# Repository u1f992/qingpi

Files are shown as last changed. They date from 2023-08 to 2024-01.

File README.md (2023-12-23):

# Qingpi





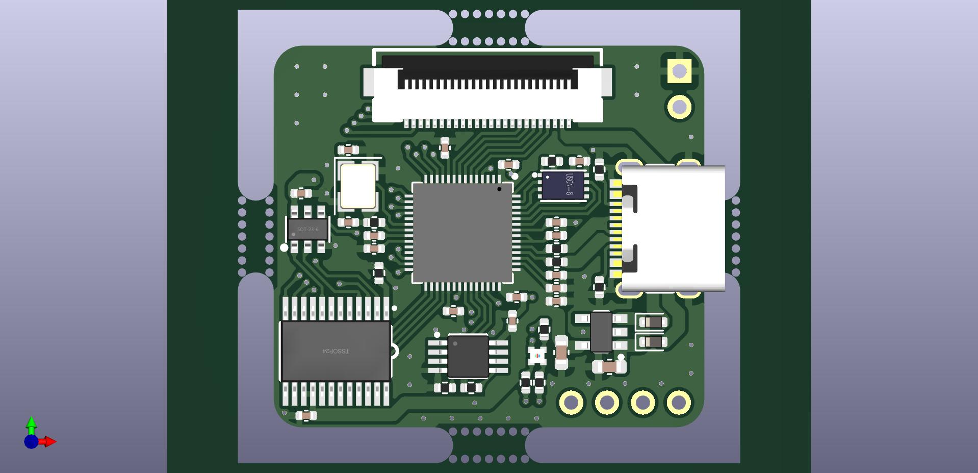
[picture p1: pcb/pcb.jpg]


Qingpi aka NeoCtrlMod is a project for externally controlling the Nintendo 3DS.

- PCB, FPC, firmware, Python library and example application included.
- Small enough to fit in a original housing.
- Buttons, slide pad, and touch screen supported.
  - IR not yet supported, but connected (contributions welcome).
- Aim to be fully documented.

Currently FPC is provided only for 3DS XL.

## Origin of the name

Qing Pi (青皮) is a herbal remedy made from the peel of unripe citrus fruits. It is named after [Citra](https://citra-emu.org/), the famous 3DS emulator, and "Citra" is derived from "CTR", the model number of 3DS series.

## Disclaimer

This is an unofficial project and the author assumes no responsibility for any 3DS hardware modifications. Use at your own risk and discretion.

## Acknowledgments

- [3DS controller mod](https://3dscapture.com/controller/) by loopy
- [3xtDS](https://github.com/dekuNukem/3xtDS) by dekuNukem
- [Nu Hanafudaya](https://kokagem.sakura.ne.jp/font/hanafudaya/) font by さゆぬ

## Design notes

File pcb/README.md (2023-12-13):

# PCB

## JLCPCB order

### PCB

<dl>
<dt>PCB Thickness</dt><dd>1.0</dd>
<dt>Remove Order Number</dt><dd>Specify a location</dd>
<dt>PCB Remark</dt><dd>Holes in the four corners are for position calibration. NPTH&F.Mask&F.Paste, drill holes in both the PCB and the stencil.</dd>
</dl>

### PCBA

<dl>
<dt>PCBA Type</dt><dd>Economic</dd>
<dt>Confirm Parts Placement</dt><dd>Yes</dd>
</dl>

### Stencil

<dl>
<dt>Customized size</dt><dd>Yes 50*85mm</dd>
<dt>Stencil Side</dt><dd>Top</dd>
<dt>Confirm Production file</dt><dd>Yes</dd>
<dt>Stencil Remark</dt><dd>Holes in the four corners are for position calibration. NPTH&F.Mask&F.Paste, drill holes in both the PCB and the stencil.</dd>
</dl>

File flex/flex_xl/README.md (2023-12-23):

# FPC for 3DS XL

## JLCPCB order

<dl>
<dt>PCB Thickness</dt><dd>0.11</dd>
<dt>Gold Fingers</dt><dd>Yes</dd>
<dt>Gold Fingers Thickness</dt><dd>0.3</dd>
<dt>Stiffener</dt><dd>Polyimide</dd>
<dt>Polyimide Thickness</dt><dd>0.25mm</dd>
<dt>Confirm Production file</dt><dd>Yes</dd>
<dt>PCB Remark</dt><dd>

```
The placement instruction for the stiffener is included in flex-User-Comments.gbr.
Stick the stiffener on the front side.
Material : Polyimide
Required total thickness : 0.3mm
```

</dd>
</dl>

`Polyimide Thickness` can be calculated with the [PI Calculator](https://jlcpcb.com/gold-fingers-PI-thickness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). It says "PI stiffener theoretical thickness： 0.2295 mm, Recommended PI stiffener thickness： 0.25 mm".

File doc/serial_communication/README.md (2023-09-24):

# シリアル通信

通信のバイナリ構造は[NX Macro Controller](https://blog.bzl-web.com/entry/2020/01/20/165719)の方式[^7]に準拠します。パッド座標は左上起点で、ニュートラルポジションは128です。右パッドは将来の更新のために予約されています。

Switchのキーボード操作に使用されている末尾3バイトをタッチスクリーン操作に割り当てます。タッチ入力座標は左上起点で1 <= x <= 320、1 <= y <= 240の値を受け付けます。いずれかが範囲外の場合、タッチ入力を解除します。

| Index | Value |
| ----- | --- |
| 0 | 0xAB |
| 1 | Button lower |
| 2 | Button upper |
| 3 | Hat |
| 4 | Left pad X-axis |
| 5 | Left pad Y-axis |
| 6 | (Right pad X-axis) |
| 7 | (Right pad Y-axis) |
| 8 | Touch screen X-axis lower |
| 9 | Touch screen X-axis upper |
| 10 | Touch screen Y-axis |

ボタンは各ビットについて0を解放、1を押下とします。ZLとZRは将来の更新のために予約されています。対応するボタンが存在しないL ClickとR Clickには、電源とWi-Fi切替を割り当てています。

| Button (NXMC) | Bit mask |
| --- | --- |
| Y | 0b0000'0000'0000'0001 |
| B | 0b0000'0000'0000'0010 |
| A | 0b0000'0000'0000'0100 |
| X | 0b0000'0000'0000'1000 |
| L | 0b0000'0000'0001'0000 |
| R | 0b0000'0000'0010'0000 |
| (ZL) | 0b0000'0000'0100'0000 |
| (ZR) | 0b0000'0000'1000'0000 |
| (-) → Select | 0b0000'0001'0000'0000 |
| (+) → Start | 0b0000'0010'0000'0000 |
| (L Click) → Power | 0b0000'0100'0000'0000 |
| (R Click) → Wi-Fi | 0b0000'1000'0000'0000 |
| Home | 0b0001'0000'0000'0000 |
| (Capture) | 0b0010'0000'0000'0000 |

ハットの各方向の実体はボタンですが、押し方の組み合わせは機構上制限されています。

| Hat | Value |
| --- | ----- |
| ↑ | 0 |
| ↗ | 1 |
| → | 2 |
| ↘ | 3 |
| ↓ | 4 |
| ↙ | 5 |
| ← | 6 |
| ↖ | 7 |
| x | 8 |

[^7]: https://scrapbox.io/yatsuna827827-12010999/Nintendo_Switch%E3%82%92%E6%93%8D%E4%BD%9C%E3%81%99%E3%82%8B%E3%83%97%E3%83%AD%E3%82%B0%E3%83%A9%E3%83%A0%E3%81%AE%E4%BB%9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

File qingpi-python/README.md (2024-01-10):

# qingpi-python

Python library for Qingpi.

```shell-session
$ pip install qingpi-python
```

## qingpictl

GUI application to control Qingpi with transparent Window and Citra compatible keyboard operation.

Currently, only Windows version is available.

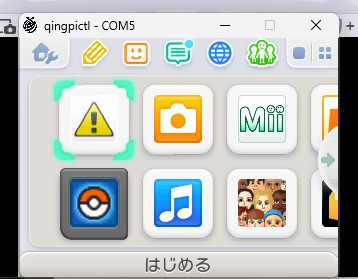
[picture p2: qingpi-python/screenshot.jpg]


### Run

```shell-session
$ qingpictl [port]
```

or

```shell-session
$ python -m qingpi [port]
```

or using pre-built binary

```shell-session
> qingpictl.exe [port]
```

You may create batch file like this if you don't want to specify the port from the command line every time.

```bat
START qingpictl.exe COM6
```

### Input mapping

<dl>
<dt>

Button

</dt>
<dd>

| Control  | Input |
| --- | :---: |
| A |  `A`  |
| B |  `S`  |
| X |  `Z`  |
| Y |  `X`  |
| L |  `Q`  |
| R |  `W`  |
| ~~ZL~~ |  `1`  |
| ~~ZR~~ |  `2`  |
| START |  `M`  |
| SELECT |  `N`  |
| HOME |  `B`  |
| POWER |  `V`  |
| WIRELESS |  `P`  |

</dd>
<dt>

Hat

</dt>
<dd>

| Control | Input |
| --- | :---: |
| UP |  `T`  |
| RIGHT |  `H`  |
| DOWN |  `G`  |
| LEFT |  `F`  |

</dd>
<dt>

SlidePad

</dt>
<dd>

| Control | Input |
| --- | :---: |
| UP |  `<Up>` |
| RIGHT | `<Right>` |
| DOWN | `<Down>`  |
| LEFT | `<Left>`  |

</dd>
<dt>

~~Circle Pad Pro~~ (not implemented)

</dt>
<dd>

| Control | Input |
| --- | :---: |
| ~~UP~~ |  `I`  |
| ~~RIGHT~~ |  `L`  |
| ~~DOWN~~  |  `K`  |
| ~~LEFT~~  |  `J`  |

</dd>
<dt>

Hotkeys

</dt>
<dd>

| Control | Input |
| --- | :---: |
| Expand window |  `+`  |
| Shrink window |  `-`  |

</dd>
</dl>

## Developer note

```shell-session
$ poetry run python -m qingpi [port] --debug
```

The build script requires PyInstaller and ImageMagick.

```shell-session
$ poetry run python -m pip install pyinstaller
$ make
```

PyInstaller is not included in the dev group because PyInstaller has a narrower Python version specification than necessary (e.g. v6.3.0 requires "<3.13,>=3.8"), which affects version reqirements of qingpi-python.

To avoid security issues,

```shell-session
$ poetry run python -m pip uninstall pyinstaller
$ git clone https://github.com/pyinstaller/pyinstaller --depth 1
$ cd .\pyinstaller\bootloader\
$ py .\waf distclean all
$ cd ..\..\
$ poetry run python -m pip install .\pyinstaller\
```

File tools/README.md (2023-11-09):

# tools

Tools for development.

```
poetry run python [script]
```

<dl>
<dt>

`calibrate_slidepad.py [port]`

</dt>
<dd>

Rotate the slidepad significantly along its circumference.

</dd>
<dt>

`plot_image.py [input] [port]`

</dt>
<dd>

Plot the image with dots.

</dd>
<dt>

`write_line.py [port]`

</dt>
<dd>

Draw crosshairs and outer border lines.

</dd>
</dl>

## Acknowledgments

- Emoji from [Fluent Emoji](https://github.com/microsoft/fluentui-emoji)

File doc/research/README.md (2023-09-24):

# 調査メモ

## 本体の選定

3DSシリーズにはいくつか種別があります。3DSと3DS LLではTPはほぼ共通[^1]です。New 3DS以降はTP番号がシルク印刷されていませんが、以下で紹介するほぼすべての要素に対応するTPおよびビア等が明らかになっています[^2]。

| 種別 | 特徴 |
| --- | --- |
| 3DS（o3DS） | 入手しやすい。キャプチャ基板の取り付けが比較的容易[^3]だが、本体内にスペースの余裕がない。 |
| 3DS LL（XL） | キャプチャ基板の取り付けが比較的容易[^4]で、本体内に基板を収める余裕がある。 |
| New 3DSシリーズ | 本体性能が向上し、New専用ソフトもある。<br>キャプチャ基板の取り付けが高難易度、現実的ではない[^5]。操作用のTP等も同様。 |
| 2DSシリーズ | （知見が少ないため除外） |

自動操作に対応できないゲームソフトが出てきますが、他改造との共存のしやすさと工作精度の懸念から、3DS LLをベースに開発を進めます。

[^1]: http://problemkaputt.de/gbatek-3ds-testpoints.htm
[^2]: http://imaginglabo.web.fc2.com/new3DSLL-barabara.html
[^3]: https://optimize.ath.cx/N-SPA3/index.htm
[^4]: https://optimize.ath.cx/LL-SPA3/index.htm
[^5]: https://optimize.ath.cx/NEW3DS/index.htm

## ボタン

| Function  | TP  |
| --- | --- |
| Y | 88  |
| B | 92  |
| A | 89  |
| X | 86  |
| L | 83  |
| R | 82  |
| Select | 81  |
| Start | 80  |
| Home | 55  |
| 電源 | 52  |
| Wi-Fi切替 | 58  |
| ↑ | 85  |
| → | 90  |
| ↓ | 91  |
| ← | 87  |

押下されることでランド同士が導通する一般的な構造です。15個のTPが露出しており、それぞれアクティブローのデジタル入力です。解放時は1.8V出力ではなくハイインピーダンス状態にすることで、レベル変換が不要になります。

## スライドパッド

| Function | TP  |
| --- | --- |
| X軸 | 69  |
| Y軸 | 68  |

2基のポテンショメータで構成されます。フレキシブルケーブルの4線は、GND、X軸出力、1.8V、Y軸出力に対応します。X軸は右から左、Y軸は下から上に0～1.8Vのアナログ入力です。



スライドパッドが取り付けられておりニュートラルポジションの状態では、各TPは約0.9Vの状態です。電圧を変化させるには、±250μAのシンク／ソースを切り替えられる、電流出力のD/Aコンバータが必要です。ニュートラルより右／下に動かすときはシンク電流で電圧を下げ、左／上に動かすときはソース電流で電圧を上げます。

## タッチスクリーン

| Function | TP  |
| --- | --- |
| X+ | 216 |
| X- | 215 |
| Y+ | 213 |
| Y- | 214 |

タッチスクリーンの原理として、X軸とY軸にそれぞれ1基のポテンショメータが搭載されており、押下されることでワイパー同士が接続される状態をイメージしてください。



3DSでは、4つのピンの機能を以下のように操作することで、押下の検出と各座標の取得を行います（指定のないピンはハイインピーダンス状態と考えられます）。

- Y+をプルアップ回路付きデジタル入力、X-をLOWとして押下を検知 → 以下の割り込み処理を発火
- X+をHIGH、X-をLOW、Y+をアナログ入力とすることで、X座標を取得
- Y+をHIGH、Y-をLOW、X+をアナログ入力とすることで、Y座標を取得

3xtDSではピンを監視し時間を計測してX+とY+に直接アナログ出力をしていましたが、マイクロ秒精度の制御が必要であるほか、タッチ入力がブロッキング処理になりタッチしながらほかの操作を受け付けられない、境界値付近の入力は困難という課題がありました。

このプロジェクトでは、X+〜X-間とY+〜Y-間にデジタルポテンショメータを接続し、ワイパー同士をリレーを挟んで接続します。リレーがオンになることでY+はLOWになり、両方向で分圧回路が成立します。解放時はリレーをオフにするとともにデジタルポテンショメータもシャットダウンすることで、本体のタッチ入力機能を維持できます。



3DS LLにおいて実際のタッチスクリーンの全抵抗値は、X軸方向が約460Ω、Y軸方向が約360Ωです。プルアップ抵抗値は不明ですが、全抵抗値が可能な限り低いデジタルポテンショメータを使用する必要があると考えられます。実験の結果、X軸に全抵抗値2kΩ、Y軸に1kΩのポテンショメータとするのは問題ないようです。

執筆時点で、市販品には1kΩ未満の高分解能なデジタルポテンショメータはありません。Y軸の240pxは8bitで対応できますが、X軸の320pxを指定するために、3基のポテンショメータを使用することで対処しています[^6]。

[^6]: https://www.analog.com/media/en/technical-documentation/application-notes/AN-582.pdf

## 拡張スライドパッド／赤外線

TP255に露出していることはわかっていますが、詳細はわかりません。

Controller Modには拡張スライドパッドのエミュレーション機能がありますが、もとがPSoCなうえアセンブリ言語も用いているので移植が困難です。PIOも別コアも空いているので、気概さえあれば実装できます。

## 電源

+5.0Vからマイコンに電力を供給します。

| 電圧 | TP  |
| ---- | --- |
| +5.0 | 32  |
| GND  | 1 |

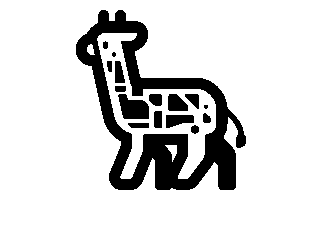
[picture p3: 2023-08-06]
tools/giraffe.png

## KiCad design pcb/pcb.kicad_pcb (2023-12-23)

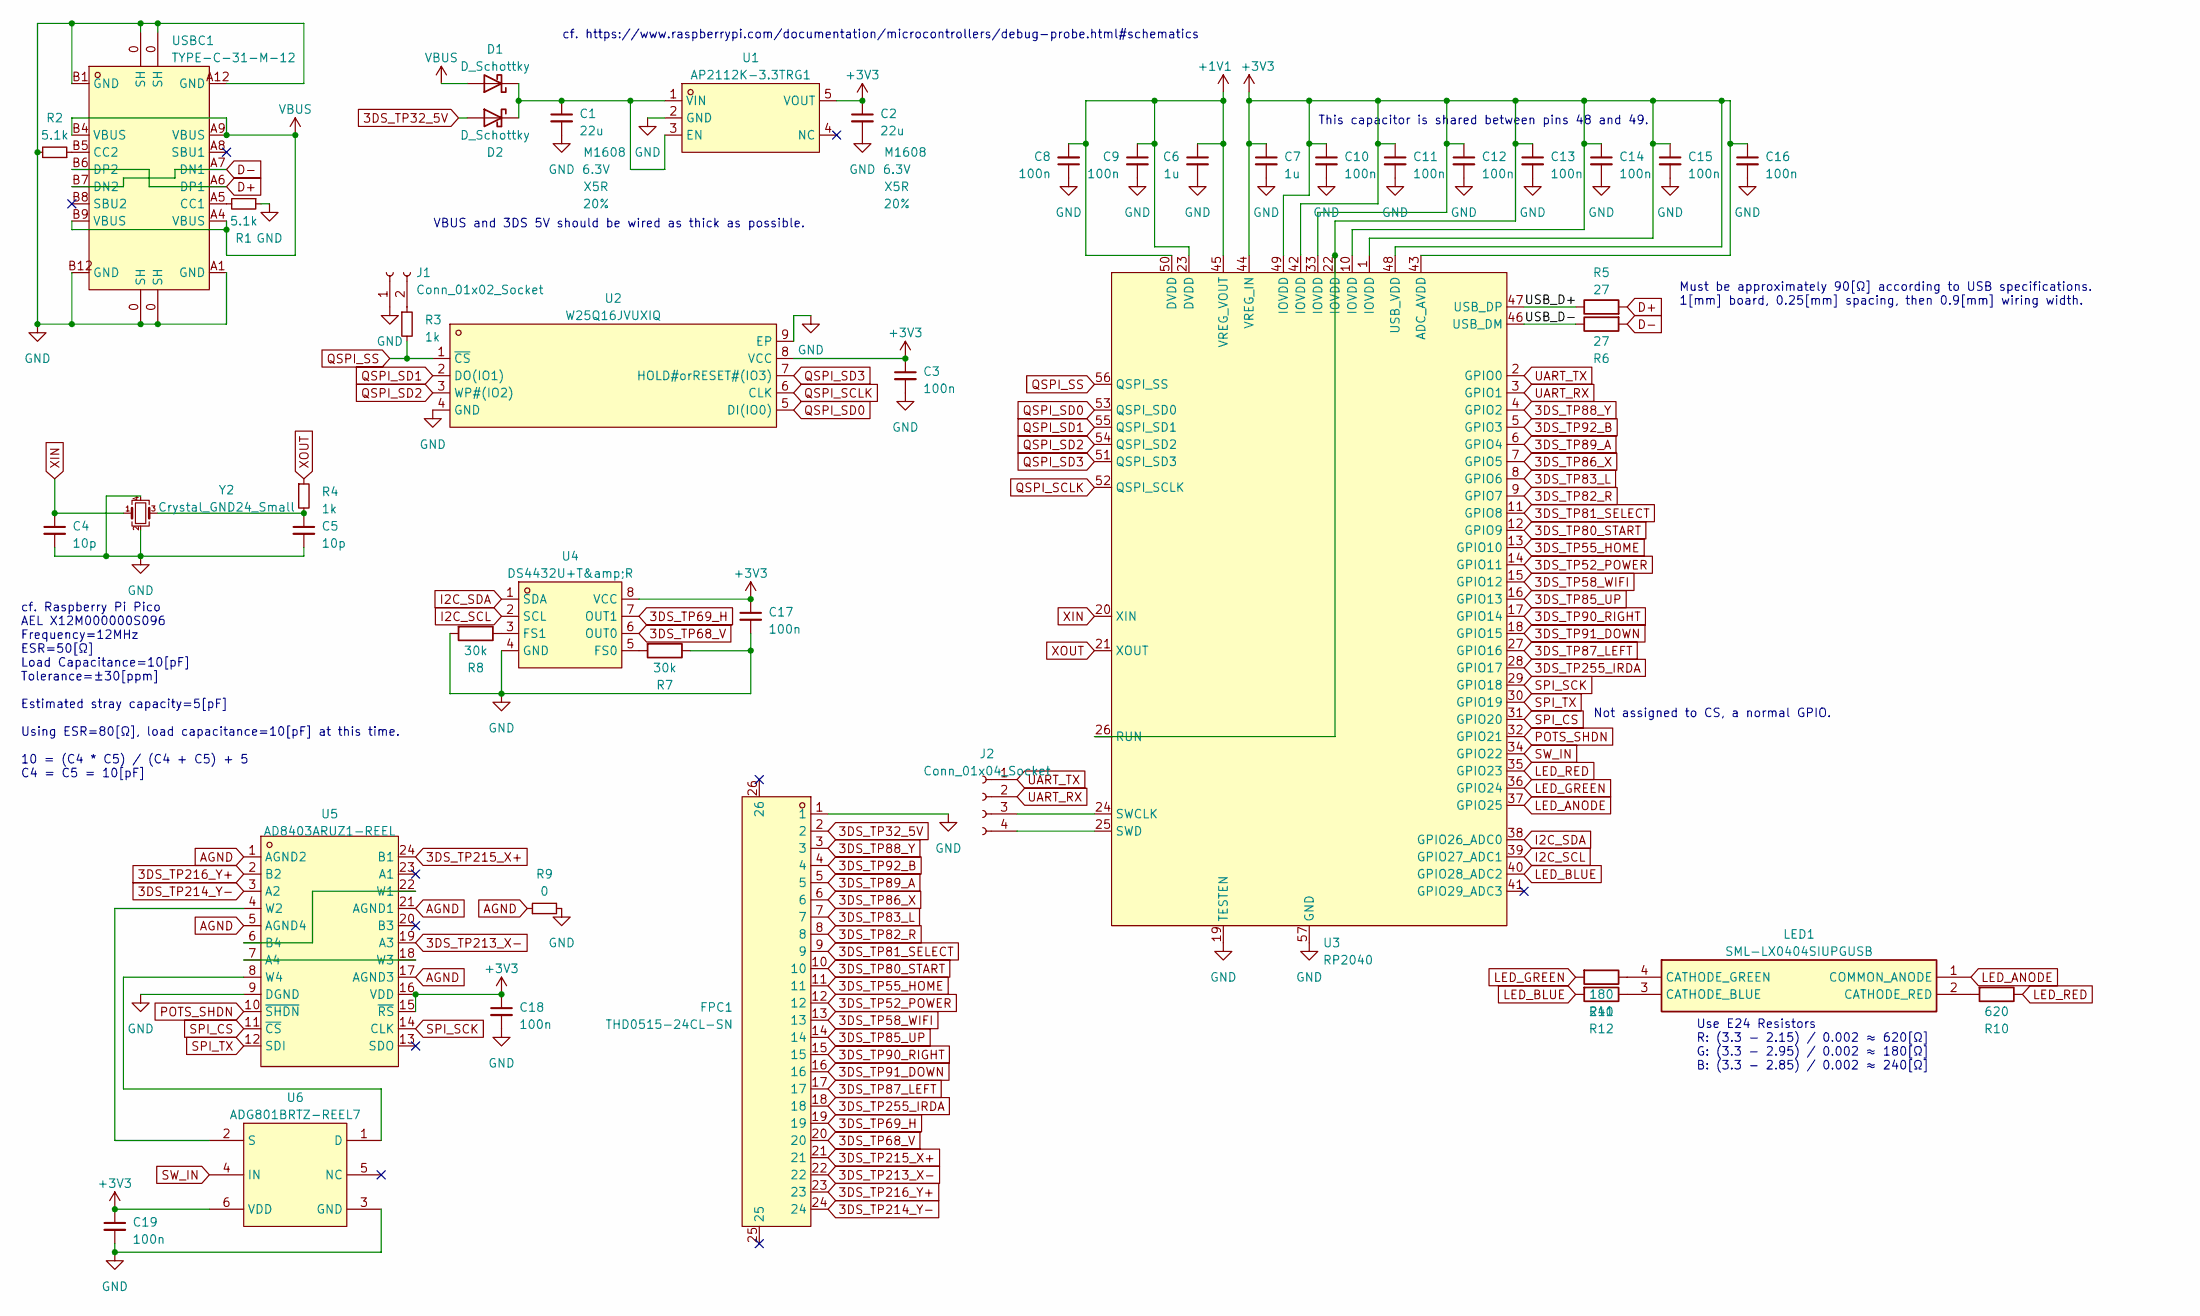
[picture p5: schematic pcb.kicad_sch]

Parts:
C1, C2: 22u; C_0603_1608Metric; LCSC C3015158
C3, C8, C9, C10, C11, C12, C13, C14, C15, C16, C17, C18, C19: 100n; C_0402_1005Metric
C4, C5: 10p; C_0402_1005Metric
C6, C7: 1u; C_0402_1005Metric
D1, D2: D_Schottky; D_SOD-523; LCSC C99683
FPC1: THD0515-24CL-SN; FPC-SMD_24P-P0.50_THD0515-24CL-SN; LCSC Part C283150
J1: Conn_01x02_Socket; PinSocket_1x02_P2.54mm_Vertical
J2: Conn_01x04_Socket; PinSocket_1x04_P2.54mm_Vertical
LED1: SML-LX0404SIUPGUSB; Manufacturer_Part_Number SML-LX0404SIUPGUSB; Mouser Part Number 696-LX0404SIUPGUSB
R1, R2: 5.1k; R_0402_1005Metric
R3, R4: 1k; R_0402_1005Metric
R5, R6: 27; R_0402_1005Metric
R7, R8: 30k; R_0402_1005Metric
R9: 0; R_0402_1005Metric
R10: 620; R_0402_1005Metric
R11: 180; R_0402_1005Metric
R12: 240; R_0402_1005Metric
U1: AP2112K-3.3TRG1; SOT-25-5_L2.9-W1.6-P0.95-LS2.8-BL; LCSC Part C51118
U2: W25Q16JVUXIQ; USON-8_L3.0-W2.0-P0.50-BL-EP; LCSC Part C2843335
U3: RP2040; LQFN-56_L7.0-W7.0-P0.4-EP; LCSC Part C2040
U4: DS4432U+T&amp;R; UMAX-8_L3.0-W3.0-P0.65-LS4.9-BL; LCSC Part C2679620
U5: AD8403ARUZ1-REEL; TSSOP-24_L7.8-W4.4-P0.65-LS6.4-BL; LCSC Part C652783
U6: ADG801BRTZ-REEL7; SOT-23-6_L2.9-W1.6-P0.95-LS2.8-BL; LCSC Part C208016
USBC1: TYPE-C-31-M-12; USB-C_SMD-TYPE-C-31-M-12; LCSC Part C165948
Y2: Crystal_GND24_Small; Crystal_SMD_3225-4Pin_3.2x2.5mm; LCSC C9002

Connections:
3DS_TP32_5V: D2.2 (A), FPC1.2
3DS_TP52_POWER: FPC1.12, U3.14 (GPIO11)
3DS_TP55_HOME: FPC1.11, U3.13 (GPIO10)
3DS_TP58_WIFI: FPC1.13, U3.15 (GPIO12)
3DS_TP68_V: FPC1.20, U4.6 (OUT0)
3DS_TP69_H: FPC1.19, U4.7 (OUT1)
3DS_TP80_START: FPC1.10, U3.12 (GPIO9)
3DS_TP81_SELECT: FPC1.9, U3.11 (GPIO8)
3DS_TP82_R: FPC1.8, U3.9 (GPIO7)
3DS_TP83_L: FPC1.7, U3.8 (GPIO6)
3DS_TP85_UP: FPC1.14, U3.16 (GPIO13)
3DS_TP86_X: FPC1.6, U3.7 (GPIO5)
3DS_TP87_LEFT: FPC1.17, U3.27 (GPIO16)
3DS_TP88_Y: FPC1.3, U3.4 (GPIO2)
3DS_TP89_A: FPC1.5, U3.6 (GPIO4)
3DS_TP90_RIGHT: FPC1.15, U3.17 (GPIO14)
3DS_TP91_DOWN: FPC1.16, U3.18 (GPIO15)
3DS_TP92_B: FPC1.4, U3.5 (GPIO3)
3DS_TP213_X-: FPC1.22, U5.19 (A3)
3DS_TP214_Y-: FPC1.24, U5.3 (A2)
3DS_TP215_X+: FPC1.21, U5.24 (B1)
3DS_TP216_Y+: FPC1.23, U5.2 (B2)
3DS_TP255_IRDA: FPC1.18, U3.28 (GPIO17)
+1V1: C6.1, C8.2, C9.1, U3.23 (DVDD), U3.45 (VREG_VOUT), U3.50 (DVDD)
+3V3: C2.1, C3.1, C7.1, C10.1, C11.1, C12.1, C13.1, C14.1, C15.1, C16.1, C17.1, C18.1, C19.1, U1.5 (VOUT), U2.8 (VCC), U3.1 (IOVDD), U3.10 (IOVDD), U3.22 (IOVDD), U3.26 (RUN), U3.33 (IOVDD), U3.42 (IOVDD), U3.43 (ADC_AVDD), U3.44 (VREG_IN), U3.48 (USB_VDD), U3.49 (IOVDD), U4.8 (VCC), U5.15 (~RS), U5.16 (VDD), U6.6 (VDD)
/USB_D+: R5.1, U3.47 (USB_DP)
/USB_D-: R6.1, U3.46 (USB_DM)
AGND: R9.1, U5.1 (AGND2), U5.5 (AGND4), U5.17 (AGND3), U5.21 (AGND1)
D+: R5.2, USBC1.A6 (DP1), USBC1.B6 (DP2)
D-: R6.2, USBC1.A7 (DN1), USBC1.B7 (DN2)
GND: C1.2, C2.2, C3.2, C4.2, C5.2, C6.2, C7.2, C8.1, C9.2, C10.2, C11.2, C12.2, C13.2, C14.2, C15.2, C16.2, C17.2, C18.2, C19.2, FPC1.1, J1.1, R1.1, R2.2, R7.1, R8.2, R9.2, U1.2 (GND), U2.4 (GND), U2.9 (EP), U3.19 (TESTEN), U3.57 (GND), U4.4 (GND), U5.9 (DGND), U6.3 (GND), USBC1.0 (SH), USBC1.A1 (GND), USBC1.A12 (GND), USBC1.B1 (GND), USBC1.B12 (GND), Y2.2, Y2.4
I2C_SCL: U3.39 (GPIO27_ADC1), U4.2 (SCL)
I2C_SDA: U3.38 (GPIO26_ADC0), U4.1 (SDA)
LED_ANODE: LED1.1 (COMMON_ANODE), U3.37 (GPIO25)
LED_BLUE: R12.2, U3.40 (GPIO28_ADC2)
LED_GREEN: R11.2, U3.36 (GPIO24)
LED_RED: R10.1, U3.35 (GPIO23)
unnamed: C5.1, R4.2, Y2.3
unnamed: C1.1, D1.1 (K), D2.1 (K), U1.1 (VIN), U1.3 (EN)
unnamed: J1.2, R3.1
unnamed: J2.3, U3.24 (SWCLK)
unnamed: J2.4, U3.25 (SWD)
unnamed: LED1.3 (CATHODE_BLUE), R12.1
unnamed: LED1.4 (CATHODE_GREEN), R11.1
unnamed: LED1.2 (CATHODE_RED), R10.2
unnamed: R7.2, U4.5 (FS0)
unnamed: R8.1, U4.3 (FS1)
unnamed: U5.7 (A4), U5.18 (W3)
unnamed: U5.6 (B4), U5.22 (W1)
unnamed: U5.4 (W2), U6.2 (S)
unnamed: U5.8 (W4), U6.1 (D)
unnamed: R1.2, USBC1.A5 (CC1)
unnamed: R2.1, USBC1.B5 (CC2)
POTS_SHDN: U3.32 (GPIO21), U5.10 (~SHDN)
QSPI_SCLK: U2.6 (CLK), U3.52 (QSPI_SCLK)
QSPI_SD0: U2.5 (DI(IO0)), U3.53 (QSPI_SD0)
QSPI_SD1: U2.2 (DO(IO1)), U3.55 (QSPI_SD1)
QSPI_SD2: U2.3 (WP#(IO2)), U3.54 (QSPI_SD2)
QSPI_SD3: U2.7 (HOLD#orRESET#(IO3)), U3.51 (QSPI_SD3)
QSPI_SS: R3.2, U2.1 (~CS), U3.56 (QSPI_SS)
SPI_CS: U3.31 (GPIO20), U5.11 (~CS)
SPI_SCK: U3.29 (GPIO18), U5.14 (CLK)
SPI_TX: U3.30 (GPIO19), U5.12 (SDI)
SW_IN: U3.34 (GPIO22), U6.4 (IN)
UART_RX: J2.2, U3.3 (GPIO1)
UART_TX: J2.1, U3.2 (GPIO0)
VBUS: D1.2 (A), USBC1.A4 (VBUS), USBC1.A9 (VBUS), USBC1.B4 (VBUS), USBC1.B9 (VBUS)
XIN: C4.1, U3.20 (XIN), Y2.1
XOUT: R4.1, U3.21 (XOUT)

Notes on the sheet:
Not assigned to CS, a normal GPIO.
Must be approximately 90[Ω] according to USB specifications. 1[mm] board, 0.25[mm] spacing, then 0.9[mm] wiring width.
cf. Raspberry Pi Pico AEL X12M000000S096 Frequency=12MHz ESR=50[Ω] Load Capacitance=10[pF] Tolerance=±30[ppm] Estimated stray capacity=5[pF] Using ESR=80[Ω], load capacitance=10[pF] at this time. 10 = (C4 * C5) / (C4 + C5) + 5 C4 = C5 = 10[pF]
Use E24 Resistors R: (3.3 - 2.15) / 0.002 ≈ 620[Ω] G: (3.3 - 2.95) / 0.002 ≈ 180[Ω] B: (3.3 - 2.85) / 0.002 ≈ 240[Ω]
cf. https://www.raspberrypi.com/documentation/microcontrollers/debug-probe.html#schematics
VBUS and 3DS 5V should be wired as thick as possible.
This capacitor is shared between pins 48 and 49.

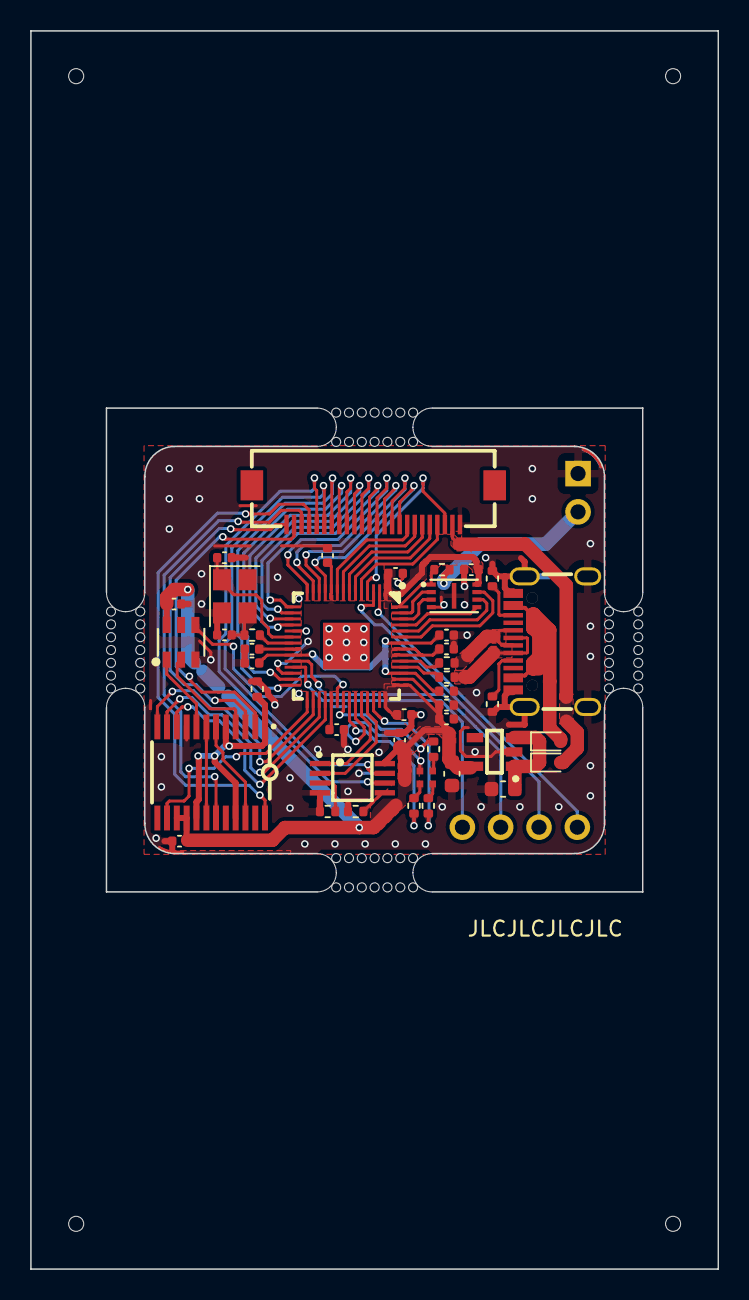
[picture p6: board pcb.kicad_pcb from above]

Board: 2 copper layers, 45.6 x 82.1 mm, 45 parts (0 on the bottom side), 69 nets.

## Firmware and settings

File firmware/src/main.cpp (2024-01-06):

#include <Arduino.h>
#include <SPI.h>
#include <Wire.h>

#include "qingpi.h"
#include "qingpi_adapters.h"

#include "nxamf.h"
#include "nxamf/nxmc2.h"
#include "nxamf/pokecon.h"

#include "ctinypalette.h"
#include "sml_lx0404siupgusb.h"
#include "sml_lx0404siupgusb_arduino_adapter.h"

#define QINGPI_XL
#ifdef QINGPI_XL
static const pin_size_t PIN_SELECT = 2;
static const pin_size_t PIN_HOME = 3;
static const pin_size_t PIN_POWER = 4;
static const pin_size_t PIN_START = 5;
static const pin_size_t PIN_LEFT = 6;
static const pin_size_t PIN_DOWN = 7;
static const pin_size_t PIN_UP = 8;
static const pin_size_t PIN_RIGHT = 9;
static const pin_size_t PIN_WIRELESS = 10;
static const pin_size_t PIN_B = 11;
static const pin_size_t PIN_X = 12;
static const pin_size_t PIN_Y = 13;
static const pin_size_t PIN_A = 14;
static const pin_size_t PIN_R = 15;
static const pin_size_t PIN_L = 16;
// static const pin_size_t PIN_IRDA = 17;
static const pin_size_t PIN_SPI_SCK = 18;
static const pin_size_t PIN_SPI_TX = 19;
static const pin_size_t PIN_SPI_CS = 20;
static const pin_size_t PIN_POTS_SHDN = 21;
static const pin_size_t PIN_SW_IN = 22;
static const pin_size_t PIN_LED_RED = 23;
static const pin_size_t PIN_LED_GREEN = 24;
static const pin_size_t PIN_LED_ANODE = 25;
static const pin_size_t PIN_I2C_SDA = 26;
static const pin_size_t PIN_I2C_SCL = 27;
static const pin_size_t PIN_LED_BLUE = 28;

static const uint16_t TOUCHSCREEN_X_MAX = 320;
static const uint8_t TOUCHSCREEN_Y_MAX = 240;
#endif

static GPIOAdapter *gpio_y = NULL;
static QpiButton *btn_y = NULL;
static GPIOAdapter *gpio_b = NULL;
static QpiButton *btn_b = NULL;
static GPIOAdapter *gpio_a = NULL;
static QpiButton *btn_a = NULL;
static GPIOAdapter *gpio_x = NULL;
static QpiButton *btn_x = NULL;
static GPIOAdapter *gpio_l = NULL;
static QpiButton *btn_l = NULL;
static GPIOAdapter *gpio_r = NULL;
static QpiButton *btn_r = NULL;
static GPIOAdapter *gpio_select = NULL;
static QpiButton *btn_select = NULL;
static GPIOAdapter *gpio_start = NULL;
static QpiButton *btn_start = NULL;
static GPIOAdapter *gpio_home = NULL;
static QpiButton *btn_home = NULL;
static GPIOAdapter *gpio_power = NULL;
static QpiButton *btn_power = NULL;
static GPIOAdapter *gpio_wireless = NULL;
static QpiButton *btn_wireless = NULL;

static GPIOAdapter *gpio_up = NULL;
static QpiButton *hat_up = NULL;
static GPIOAdapter *gpio_right = NULL;
static QpiButton *hat_right = NULL;
static GPIOAdapter *gpio_down = NULL;
static QpiButton *hat_down = NULL;
static GPIOAdapter *gpio_left = NULL;
static QpiButton *hat_left = NULL;
static QpiHat *hat = NULL;

static DS4432 *dac = NULL;
static DS4432Adapter *dac_v = NULL;
static DS4432Adapter *dac_h = NULL;
static QpiSlidePad *sp = NULL;

static AD840X *pots = NULL;
static AD840XAdapter *pots_v = NULL;
static AD840XTripleAdapter *pots_h = NULL;
static ADG801 *sw = NULL;
static ADG801Adapter *sw_adapter = NULL;
static QpiTouchScreen *ts = NULL;

static const int ANALOG_WRITE_RESOLUTION = 16;
static SML_LX0404SIUPGUSBArduinoDigitalAdapter *anode;
static SML_LX0404SIUPGUSBArduinoAnalogAdapter *pwm_red;
static SML_LX0404SIUPGUSBArduinoAnalogAdapter *pwm_green;
static SML_LX0404SIUPGUSBArduinoAnalogAdapter *pwm_blue;
static SML_LX0404SIUPGUSB *led;

static const int SERIAL_INACTIVE_TIMEOUT = 100;
static int inactive_count = 0;

static Nxmc2Protocol *nxmc2;
static PokeConProtocol *pokecon;
static NxamfBytesProtocolInterface *protocols[2];
static NxamfProtocolMultiplexer *mux;
static NxamfBytesBuffer *buffer;

static int64_t led_off(alarm_id_t id, void *user_data)
{
    sml_lx0404siupgusb_off(led);
    return false;
}

static void async_led_on_for_100ms()
{
    sml_lx0404siupgusb_on(led);
    alarm_id_t alarm_id = add_alarm_in_ms(100, led_off, NULL, false);
}

static void reflect_state(NxamfGamepadState *state)
{
    if (state == NULL)
    {
        return;
    }

    uint16_t r = SML_LX0404SIUPGUSB_OFF;
    uint16_t g = SML_LX0404SIUPGUSB_OFF;
    uint16_t b = SML_LX0404SIUPGUSB_OFF;

    if (state->y == NXAMF_BUTTON_STATE_PRESSED)
    {
        qpi_button_hold(btn_y);
        r = SML_LX0404SIUPGUSB_ON;
    }
    else
    {
        qpi_button_release(btn_y);
    }

    if (state->b == NXAMF_BUTTON_STATE_PRESSED)
    {
        qpi_button_hold(btn_b);
        r = SML_LX0404SIUPGUSB_ON;
    }
    else
    {
        qpi_button_release(btn_b);
    }

    if (state->a == NXAMF_BUTTON_STATE_PRESSED)
    {
        qpi_button_hold(btn_a);
        r = SML_LX0404SIUPGUSB_ON;
    }
    else
    {
        qpi_button_release(btn_a);
    }

    if (state->x == NXAMF_BUTTON_STATE_PRESSED)
    {
        qpi_button_hold(btn_x);
        r = SML_LX0404SIUPGUSB_ON;
    }
    else
    {
        qpi_button_release(btn_x);
    }

    if (state->l == NXAMF_BUTTON_STATE_PRESSED)
    {
        qpi_button_hold(btn_l);
        r = SML_LX0404SIUPGUSB_ON;
    }
    else
    {
        qpi_button_release(btn_l);
    }

    if (state->r == NXAMF_BUTTON_STATE_PRESSED)
    {
        qpi_button_hold(btn_r);
        r = SML_LX0404SIUPGUSB_ON;
    }
    else
    {
        qpi_button_release(btn_r);
    }

    if (state->minus == NXAMF_BUTTON_STATE_PRESSED)
    {
        qpi_button_hold(btn_select);
        r = SML_LX0404SIUPGUSB_ON;
    }
    else
    {
        qpi_button_release(btn_select);
    }

    if (state->plus == NXAMF_BUTTON_STATE_PRESSED)
    {
        qpi_button_hold(btn_start);
        r = SML_LX0404SIUPGUSB_ON;
    }
    else
    {
        qpi_button_release(btn_start);
    }

    if (state->home == NXAMF_BUTTON_STATE_PRESSED)
    {
        qpi_button_hold(btn_home);
        r = SML_LX0404SIUPGUSB_ON;
    }
    else
    {
        qpi_button_release(btn_home);
    }

    if (state->l_click == NXAMF_BUTTON_STATE_PRESSED)
    {
        qpi_button_hold(btn_power);
        r = SML_LX0404SIUPGUSB_ON;
    }
    else
    {
        qpi_button_release(btn_power);
    }

    if (state->r_click == NXAMF_BUTTON_STATE_PRESSED)
    {
        qpi_button_hold(btn_wireless);
        r = SML_LX0404SIUPGUSB_ON;
    }
    else
    {
        qpi_button_release(btn_wireless);
    }

    switch (state->hat)
    {
    case NXAMF_HAT_STATE_UP:
        qpi_hat_hold(hat, QPI_HAT_UP);
        r = SML_LX0404SIUPGUSB_ON;
        g = SML_LX0404SIUPGUSB_ON;
        break;
    case NXAMF_HAT_STATE_UPRIGHT:
        qpi_hat_hold(hat, QPI_HAT_UPRIGHT);
        r = SML_LX0404SIUPGUSB_ON;
        g = SML_LX0404SIUPGUSB_ON;
        break;
    case NXAMF_HAT_STATE_RIGHT:
        qpi_hat_hold(hat, QPI_HAT_RIGHT);
        r = SML_LX0404SIUPGUSB_ON;
        g = SML_LX0404SIUPGUSB_ON;
        break;
    case NXAMF_HAT_STATE_DOWNRIGHT:
        qpi_hat_hold(hat, QPI_HAT_DOWNRIGHT);
        r = SML_LX0404SIUPGUSB_ON;
        g = SML_LX0404SIUPGUSB_ON;
        break;
    case NXAMF_HAT_STATE_DOWN:
        qpi_hat_hold(hat, QPI_HAT_DOWN);
        r = SML_LX0404SIUPGUSB_ON;
        g = SML_LX0404SIUPGUSB_ON;
        break;
    case NXAMF_HAT_STATE_DOWNLEFT:
        qpi_hat_hold(hat, QPI_HAT_DOWNLEFT);
        r = SML_LX0404SIUPGUSB_ON;
        g = SML_LX0404SIUPGUSB_ON;
        break;
    case NXAMF_HAT_STATE_LEFT:
        qpi_hat_hold(hat, QPI_HAT_LEFT);
        r = SML_LX0404SIUPGUSB_ON;
        g = SML_LX0404SIUPGUSB_ON;
        break;
    case NXAMF_HAT_STATE_UPLEFT:
        qpi_hat_hold(hat, QPI_HAT_UPLEFT);
        r = SML_LX0404SIUPGUSB_ON;
        g = SML_LX0404SIUPGUSB_ON;
        break;
    case NXAMF_HAT_STATE_NEUTRAL:
    default:
        qpi_hat_release(hat);
        break;
    }

    if (state->l_stick.x != NXAMF_STICK_STATE_NEUTRAL || state->l_stick.y != NXAMF_STICK_STATE_NEUTRAL)
    {
        qpi_slidepad_hold(sp, (uint16_t)(((double)state->l_stick.x / UINT8_MAX) * UINT16_MAX), (uint16_t)(((double)state->l_stick.y / UINT8_MAX) * UINT16_MAX));
        g = SML_LX0404SIUPGUSB_ON;
    }
    else
    {
        qpi_slidepad_release(sp);
    }

    uint16_t ts_x = state->extension[0] | state->extension[1] << 8;
    uint8_t ts_y = state->extension[2];
    if (0 < ts_x && ts_x <= TOUCHSCREEN_X_MAX && 0 < ts_y && ts_y <= TOUCHSCREEN_Y_MAX)
    {
        qpi_touchscreen_hold(ts, (uint16_t)(((double)ts_x / TOUCHSCREEN_X_MAX) * UINT16_MAX), (uint16_t)(((double)ts_y / TOUCHSCREEN_Y_MAX) * UINT16_MAX));
        b = SML_LX0404SIUPGUSB_ON;
    }
    else
    {
        qpi_touchscreen_release(ts);
    }

    sml_lx0404siupgusb_set(led, r, g, b);
    async_led_on_for_100ms();
}

void setup()
{
    Serial.begin(9600);

    pinMode(PIN_Y, INPUT);
    gpio_y = gpio_adapter_new(PIN_Y);
    btn_y = qpi_button_new((QpiGeneralPurposeIOInterface *)gpio_y);
    pinMode(PIN_B, INPUT);
    gpio_b = gpio_adapter_new(PIN_B);
    btn_b = qpi_button_new((QpiGeneralPurposeIOInterface *)gpio_b);
    pinMode(PIN_A, INPUT);
    gpio_a = gpio_adapter_new(PIN_A);
    btn_a = qpi_button_new((QpiGeneralPurposeIOInterface *)gpio_a);
    pinMode(PIN_X, INPUT);
    gpio_x = gpio_adapter_new(PIN_X);
    btn_x = qpi_button_new((QpiGeneralPurposeIOInterface *)gpio_x);
    pinMode(PIN_L, INPUT);
    gpio_l = gpio_adapter_new(PIN_L);
    btn_l = qpi_button_new((QpiGeneralPurposeIOInterface *)gpio_l);
    pinMode(PIN_R, INPUT);
    gpio_r = gpio_adapter_new(PIN_R);
    btn_r = qpi_button_new((QpiGeneralPurposeIOInterface *)gpio_r);
    pinMode(PIN_SELECT, INPUT);
    gpio_select = gpio_adapter_new(PIN_SELECT);
    btn_select = qpi_button_new((QpiGeneralPurposeIOInterface *)gpio_select);
    pinMode(PIN_START, INPUT);
    gpio_start = gpio_adapter_new(PIN_START);
    btn_start = qpi_button_new((QpiGeneralPurposeIOInterface *)gpio_start);
    pinMode(PIN_HOME, INPUT);
    gpio_home = gpio_adapter_new(PIN_HOME);
    btn_home = qpi_button_new((QpiGeneralPurposeIOInterface *)gpio_home);
    pinMode(PIN_POWER, INPUT);
    gpio_power = gpio_adapter_new(PIN_POWER);
    btn_power = qpi_button_new((QpiGeneralPurposeIOInterface *)gpio_power);
    pinMode(PIN_WIRELESS, INPUT);
    gpio_wireless = gpio_adapter_new(PIN_WIRELESS);
    btn_wireless = qpi_button_new((QpiGeneralPurposeIOInterface *)gpio_wireless);

    pinMode(PIN_UP, INPUT);
    gpio_up = gpio_adapter_new(PIN_UP);
    hat_up = qpi_button_new((QpiGeneralPurposeIOInterface *)gpio_up);
    pinMode(PIN_RIGHT, INPUT);
    gpio_right = gpio_adapter_new(PIN_RIGHT);
    hat_right = qpi_button_new((QpiGeneralPurposeIOInterface *)gpio_right);
    pinMode(PIN_DOWN, INPUT);
    gpio_down = gpio_adapter_new(PIN_DOWN);
    hat_down = qpi_button_new((QpiGeneralPurposeIOInterface *)gpio_down);
    pinMode(PIN_LEFT, INPUT);
    gpio_left = gpio_adapter_new(PIN_LEFT);
    hat_left = qpi_button_new((QpiGeneralPurposeIOInterface *)gpio_left);
    hat = qpi_hat_new(hat_up, hat_right, hat_down, hat_left);

    Wire1.setSDA(PIN_I2C_SDA);
    Wire1.setSCL(PIN_I2C_SCL);
    Wire1.begin();
    dac = ds4432_new(&Wire1);
    dac_v = ds4432_adapter_new(dac, DS4432_OUT0);
    dac_h = ds4432_adapter_new(dac, DS4432_OUT1);
    sp = qpi_slidepad_new((QpiCurrentDAConverterInterface *)dac_v, (QpiCurrentDAConverterInterface *)dac_h);

    SPI.setSCK(PIN_SPI_SCK);
    SPI.setTX(PIN_SPI_TX);
    // SPI.setCS(PIN_SPI_CS);
    pinMode(PIN_SPI_CS, OUTPUT); // PIN_SPI_CS is not assigned to CS, but a normal GPIO.
    digitalWrite(PIN_SPI_CS, HIGH);
    SPI.begin();
    pinMode(PIN_POTS_SHDN, OUTPUT);
    digitalWrite(PIN_POTS_SHDN, LOW);
    pots = ad840x_new(&SPI, PIN_SPI_CS, PIN_POTS_SHDN);
    pots_v = ad840x_adapter_new(pots, AD840X_RDAC2);
    pots_h = ad840x_triple_adapter_new(pots, AD840X_RDAC3, AD840X_RDAC1, AD840X_RDAC4);
    pinMode(PIN_SW_IN, OUTPUT);
    sw = adg801_new(PIN_SW_IN);
    sw_adapter = adg801_adapter_new(sw);
    ts = qpi_touchscreen_new((QpiDigitalPotentiometerInterface *)pots_v, (QpiDigitalPotentiometerInterface *)pots_h, (QpiSPSTSwitchInterface *)sw_adapter);

    assert(
        btn_y != NULL &&
        btn_b != NULL &&
        btn_a != NULL &&
        btn_x != NULL &&
        btn_l != NULL &&
        btn_r != NULL &&
        btn_select != NULL &&
        btn_start != NULL &&
        btn_home != NULL &&
        btn_power != NULL &&
        btn_wireless != NULL &&
        hat != NULL &&
        sp != NULL &&
        ts != NULL);

    nxmc2 = nxmc2_protocol_new();
    pokecon = pokecon_protocol_new();
    protocols[0] = (NxamfBytesProtocolInterface *)nxmc2;
    protocols[1] = (NxamfBytesProtocolInterface *)pokecon;
    mux = nxamf_protocol_multiplexer_new(protocols, 2);
    buffer = nxamf_bytes_buffer_new((NxamfBytesProtocolInterface *)mux);
    assert(
        nxmc2 != NULL &&
        pokecon != NULL &&
        mux != NULL &&
        buffer != NULL);

    analogWriteResolution(ANALOG_WRITE_RESOLUTION);
    pinMode(PIN_LED_ANODE, OUTPUT_8MA);
    digitalWrite(PIN_LED_ANODE, LOW);
    anode = sml_lx0404siupgusb_arduino_digital_adapter_new(PIN_LED_ANODE);
    pinMode(PIN_LED_RED, OUTPUT);
    digitalWrite(PIN_LED_RED, HIGH);
    pwm_red = sml_lx0404siupgusb_arduino_analog_adapter_new(PIN_LED_RED, ANALOG_WRITE_RESOLUTION);
    pinMode(PIN_LED_GREEN, OUTPUT);
    digitalWrite(PIN_LED_GREEN, HIGH);
    pwm_green = sml_lx0404siupgusb_arduino_analog_adapter_new(PIN_LED_GREEN, ANALOG_WRITE_RESOLUTION);
    pinMode(PIN_LED_BLUE, OUTPUT);
    digitalWrite(PIN_LED_BLUE, HIGH);
    pwm_blue = sml_lx0404siupgusb_arduino_analog_adapter_new(PIN_LED_BLUE, ANALOG_WRITE_RESOLUTION);
    led = sml_lx0404siupgusb_new((SML_LX0404SIUPGUSBDigitalOutputInterface *)anode,
                                 (SML_LX0404SIUPGUSBAnalogOutputInterface *)pwm_red,
                                 (SML_LX0404SIUPGUSBAnalogOutputInterface *)pwm_green,
                                 (SML_LX0404SIUPGUSBAnalogOutputInterface *)pwm_blue);
    assert(
        anode != NULL &&
        pwm_red != NULL &&
        pwm_green != NULL &&
        pwm_blue != NULL &&
        led != NULL);

    // Lights up in rainbow colors if the setup routine is successful.
    for (int hue = 0; hue < 2000; hue++)
    {
        CtpHSV16 *hsv = ctp_hsv_16_new(((double)hue / 2000) * UINT16_MAX, UINT16_MAX, UINT16_MAX);
        assert(hsv != NULL);

        CtpRGB16 *rgb = ctp_hsv_16_to_rgb_16(hsv);
        assert(rgb != NULL);
        ctp_hsv_16_delete(hsv);
        hsv = NULL;

        sml_lx0404siupgusb_set(led, rgb->red, rgb->green, rgb->blue);
        sml_lx0404siupgusb_on(led);
        delay(1);

        ctp_rgb_16_delete(rgb);
        rgb = NULL;
    }
    sml_lx0404siupgusb_off(led);
}

void loop()
{
    if (Serial.available() == 0)
    {
        inactive_count++;
        if (SERIAL_INACTIVE_TIMEOUT < inactive_count)
        {
            inactive_count = 0;
            nxamf_bytes_buffer_clear(buffer);
        }
        return;
    }
    inactive_count = 0;

    uint8_t packet = Serial.read();
    NxamfGamepadState *state = nxamf_bytes_buffer_append(buffer, packet);
    if (state == NULL)
    {
        return;
    }

    reflect_state(state);

    nxamf_gamepad_state_delete(state);
    state = NULL;
}

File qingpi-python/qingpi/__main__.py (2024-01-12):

import argparse
import base64
import tkinter as tk

import serial

import qingpi
from qingpi import *  # type: ignore

from qingpi.gui.gui import *
from qingpi.gui.button import *
from qingpi.gui.hat import *
from qingpi.gui.slidepad import *
from qingpi.gui.touchscreen import *
from qingpi.gui.icon import ICON


def on_button_change(hold: HoldFunction, release: ReleaseFunction):
    def _on_button_change(id: ButtonID, pressed: bool):
        match id:
            case ButtonID.A:
                op = A
            case ButtonID.B:
                op = B
            case ButtonID.X:
                op = X
            case ButtonID.Y:
                op = Y
            case ButtonID.L:
                op = L
            case ButtonID.R:
                op = R
            case ButtonID.ZL:
                print(f"[NotImplemented] hold/release(ZL)")
                return
            case ButtonID.ZR:
                print(f"[NotImplemented] hold/release(ZR)")
                return
            case ButtonID.START:
                op = START
            case ButtonID.SELECT:
                op = SELECT
            case ButtonID.HOME:
                op = HOME
            case ButtonID.POWER:
                op = POWER
            case ButtonID.WIRELESS:
                op = WIRELESS

        if pressed:
            hold(op)
        else:
            release(op)

    return _on_button_change


def on_hat_change(hold: HoldFunction, release: ReleaseFunction):
    def _on_hat_change(hat: HatState):
        match hat:
            case HatState.UP:
                hold(UP)
            case HatState.UPRIGHT:
                hold(UPRIGHT)
            case HatState.RIGHT:
                hold(RIGHT)
            case HatState.DOWNRIGHT:
                hold(DOWNRIGHT)
            case HatState.DOWN:
                hold(DOWN)
            case HatState.DOWNLEFT:
                hold(DOWNLEFT)
            case HatState.LEFT:
                hold(LEFT)
            case HatState.UPLEFT:
                hold(UPLEFT)
            case HatState.NEUTRAL:
                release(Hat)

    return _on_hat_change


def on_slidepad_change(hold: HoldFunction, _):
    def _on_slidepad_change(x: int, y: int):
        hold(SlidePad(x, y))

    return _on_slidepad_change


def on_ext_slidepad_change(_0, _1):  # type: ignore
    def _on_ext_slidepad_change(x: int, y: int):
        print(f"[NotImplemented] hold(ExtSlidePad({x}, {y}))")

    return _on_ext_slidepad_change


def on_touchscreen_hold(hold: HoldFunction, _):
    def _on_touchscreen_hold(x: int, y: int):
        hold(TouchScreen(x, y))

    return _on_touchscreen_hold


def on_touchscreen_release(_, release: ReleaseFunction):
    def _on_touchscreen_release():
        release(TouchScreen)

    return _on_touchscreen_release


def main() -> None:
    parser = argparse.ArgumentParser(
        prog="__main__.py",
        description="GUI application to control Qingpi with transparent Window and Citra compatible keyboard operation.",
    )
    parser.add_argument(
        "port",
        type=str,
        help="Serial port name.",
    )
    parser.add_argument("--debug", action="store_true")
    args = parser.parse_args()

    ser = serial.Serial(args.port)
    if not args.debug:
        hold, release = qingpi.init(ser)
    else:

        class DebugWriter:
            def __init__(self, ser: serial.Serial):
                self.__ser = ser

            def write(self, data: typing.Any):
                print(list(data))
                return self.__ser.write(data)

        hold, release = qingpi.init(DebugWriter(ser))

    root = tk.Tk()
    root.title(f"qingpictl - {args.port}")

    touchscreen_size = TouchScreenSize(width=320, height=240)

    root.attributes("-topmost", True)  # type: ignore
    make_window_be_resized_only_by_keypress(
        root, (touchscreen_size.width, touchscreen_size.height)
    )

    make_window_transparent(root)
    filler = create_transparent_filler(root)

    bind_button_controller(root, on_button_change(hold, release))
    bind_hat_controller(root, on_hat_change(hold, release))
    bind_slidepad_controller(root, on_slidepad_change(hold, release))
    bind_ext_slidepad_controller(root, on_ext_slidepad_change(hold, release))
    bind_touchscreen_controller(
        root,
        filler,
        touchscreen_size,
        on_touchscreen_hold(hold, release),
        on_touchscreen_release(hold, release),
    )

    # Kind of a bit buggy.
    # It won't work properly unless write it here.
    iconphoto = tk.PhotoImage(data=base64.b64decode(ICON))
    root.iconphoto(False, iconphoto)

    root.mainloop()


if __name__ == "__main__":
    main()

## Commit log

2023-05-07 Add flex project
    [flex.kicad_sch]
2023-05-14 Extend flex to touch screen
    [flex.kicad_sch]
2023-08-20 Add PCB
    [pcb.kicad_pcb, pcb.kicad_sch]
2023-08-20 Update PCB
    [pcb.kicad_pcb]
2023-09-10 Add fpc
    [flex.kicad_sch]
2023-09-24 Change pin assign
2023-10-27 Update gitignore in pcb
2023-10-27 Stash old pcb
    [pcb.kicad_pcb, pcb.kicad_sch]
2023-10-28 Change pots to use
    [pcb.kicad_pcb, pcb.kicad_sch]
2023-11-02 Add flex footprint
2023-11-04 Order ready
    [pcb.kicad_pcb, pcb.kicad_sch]
2023-11-04 Slight adjustment of GND wiring
    [pcb.kicad_pcb]
2023-11-05 Add silkscreen of logo on PCB
    [pcb.kicad_pcb]
2023-11-05 Change name
    [pcb.kicad_pcb]
2023-11-05 Adjust text
    [pcb.kicad_pcb]
2023-11-06 Rename flex project
    [flex.kicad_sch, flex_xl.kicad_sch]
2023-11-06 Change footprint name
    [flex_xl.kicad_sch]
2023-11-11 Adjust 3D model position
    [pcb.kicad_pcb]
2023-11-15 Pin assign
2023-11-18 Type-C connector stick out as much as possible
    [pcb.kicad_pcb, pcb.kicad_sch]
2023-11-18 Add fastener
    [fastener.kicad_pcb]
2023-11-27 Update flex order detail
    [fastener.kicad_pcb]
2023-11-27 Adjust FPC connector slightly to the left
    [pcb.kicad_pcb]
2023-11-27 Add GND via
    [pcb.kicad_pcb]
2023-11-27 Tweak BOOTSEL path
    [pcb.kicad_pcb]
2023-11-27 Add URL on silkscreen
    [pcb.kicad_pcb]
2023-11-27 Make the text a little bigger
    [pcb.kicad_pcb]
2023-12-02 Update schematic
    [pcb.kicad_sch]
2023-12-02 For production
    [pcb.kicad_pcb]
2023-12-02 Update pictures
    [pcb.kicad_pcb]
2023-12-11 Tweak holes
    [pcb.kicad_pcb]
2023-12-20 Add LED
2023-12-20 Change LED color according to type of operation
2023-12-23 Update PCB image
